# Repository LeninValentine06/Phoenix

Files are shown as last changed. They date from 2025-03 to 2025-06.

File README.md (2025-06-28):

# LoRa-Based Real-Time Landslide Detection System
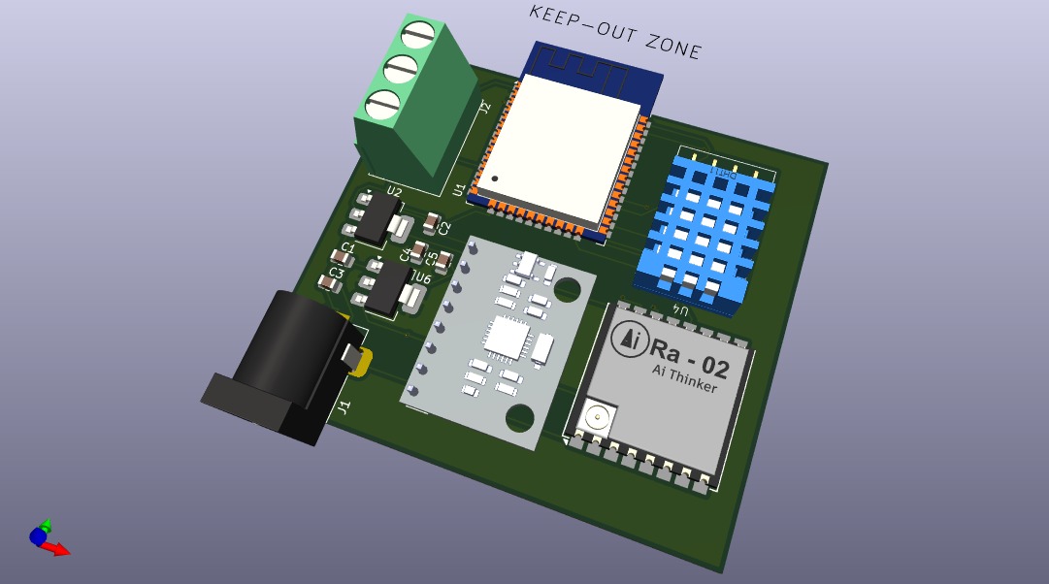
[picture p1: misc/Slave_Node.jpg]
Slave Node PCB Design
   
   *Figure 1: Slave Node PCB Design*

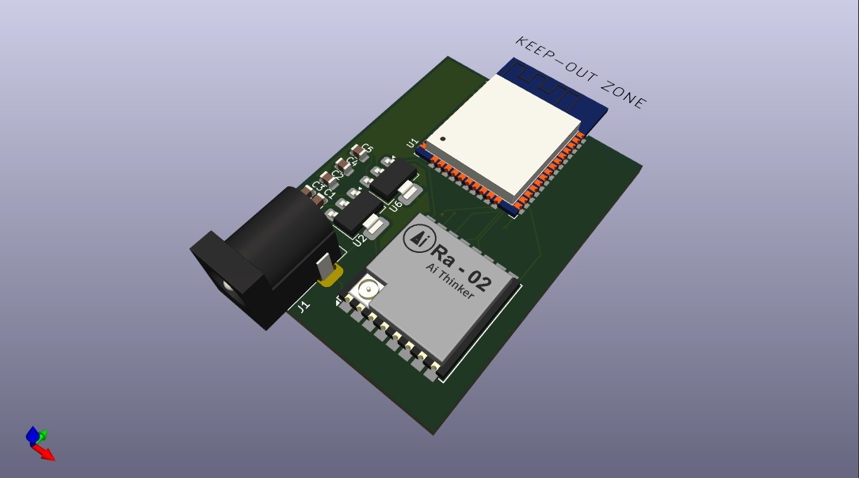
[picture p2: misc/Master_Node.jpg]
Master Node PCB Design
   
   *Figure 2: Master Node PCB Design*

## 1. Project Overview

### The Problem

Landslides are devastating natural disasters that claim thousands of lives annually worldwide. Traditional monitoring systems are often expensive, difficult to deploy in remote areas, and lack real-time alerting capabilities. Many vulnerable communities, especially in developing regions, lack access to early warning systems that could save lives.

### Our Solution

The LoRa-Based Real-Time Landslide Detection System provides an affordable, open-source solution for early detection and warning of potential landslide events. By combining low-power sensors, long-range wireless communication, and intelligent data processing, our system can:

- Detect early signs of land movement and soil condition changes
- Transmit data over long distances even in remote areas
- Provide immediate, multi-modal alerts to communities at risk
- Operate for extended periods on battery power

The system uses distributed ESP32-based sensor nodes placed in landslide-prone areas to continuously monitor ground movement, soil moisture, and environmental conditions. When potential landslide indicators are detected, the system triggers immediate alerts via multiple channels.

## 2. System Architecture

### Hardware Components

#### Sensor Node (ESP32)
- **Microcontroller**: ESP32-WROOM-32
- **Sensors**:
  - MPU6050 (3-axis accelerometer and gyroscope)
  - Capacitive soil moisture sensor
  - DHT22/AM2302 temperature and humidity sensor
- **Communication**: LoRa RA-02 module (433MHz)
- **Power**: 3.7V LiPo battery with solar charging capability

#### Master Node (ESP32)
- **Microcontroller**: ESP32-WROOM-32
- **Alert Mechanisms**:
  - 9V speaker/buzzer for audio alerts
  - 2.8" ILI9341 TFT display for visual alerts and status
  - Optional GSM module for SMS alerts
- **Communication**:
  - LoRa RA-02 module (433MHz)
  - WiFi/Bluetooth (for configuration and notifications)
- **Power**: 5V DC power supply with battery backup

### Data Flow Architecture

```
┌─────────────────┐     LoRa     ┌─────────────────┐     Alert     ┌─────────────────┐
│                 │  Wireless    │                 │   Triggers    │                 │
│   Sensor Node   │ ───────────► │   Master Node   │ ───────────► │  Alert Systems  │
│     (ESP32)     │    433MHz    │     (ESP32)     │               │   - Speaker     │
│                 │              │                 │               │   - Display     │
│                 │              │                 │               │   - Mobile      │
└─────────────────┘              └─────────────────┘               └─────────────────┘
        │                                 ▲
        │                                 │
        │         LoRa Wireless           │
        └─────────────────────────────────┘
                (Multiple Nodes)
```

1. **Data Collection**: The ESP32 sensor nodes continuously monitor accelerometer data (ground movement), soil moisture levels, and environmental conditions.
2. **Data Processing**: Initial data processing occurs on the sensor nodes to identify concerning patterns before transmission.
3. **Data Transmission**: Processed data is transmitted via LoRa to the master node.
4. **Alert Analysis**: The ESP32 master node analyzes data from multiple sensor nodes and determines if alert thresholds are exceeded.
5. **Alert Distribution**: When potential landslide conditions are detected, the master node activates local alerts and sends notifications to configured devices.

## 3. Features

### Real-time Environmental Monitoring
- Continuous accelerometer data collection at 50Hz sample rate
- Soil moisture monitoring with 5-minute intervals
- Temperature and humidity readings every 15 minutes
- Local data processing to detect movement patterns indicative of landslides

### Long-Range, Low-Power Communication
- LoRa communication with 3-10km range (depending on terrain) using 433MHz frequency
- Optimized data packets to minimize transmission power
- Node power management for extended battery life (3-6 months on a single charge with solar support)
- Reliable mesh networking capabilities between multiple sensor nodes

### Multi-Modal Alert System
- High-decibel audio alarm for immediate local warning
- Visual alerts and system status on TFT display
- Optional mobile alerts via SMS or app notifications
- Configurable alert thresholds based on local conditions

### System Scalability
- Support for up to 50 sensor nodes per master node
- Expandable with multiple master nodes for larger coverage areas
- Modular design allowing for additional sensor types
- Open API for integration with existing warning systems

## 4. Setup & Installation

### Prerequisites

#### Hardware Requirements
- ESP32 development boards (for both sensor and master nodes)
- MPU6050 accelerometer/gyroscope module
- Soil moisture sensor (capacitive recommended)
- DHT22/AM2302 temperature & humidity sensor
- LoRa RA-02 modules (433MHz)
- 2.8" ILI9341 TFT display
- 9V speaker/buzzer
- 3.7V LiPo batteries with solar charging modules
- Power supplies, jumper wires, and prototyping boards

#### Software Requirements
- Arduino IDE (for ESP32 programming)
- Required libraries (included in the repository):
  - RadioHead library for LoRa communication
  - Adafruit MPU6050 library
  - Adafruit DHT sensor library
  - Adafruit GFX & ILI9341 libraries

### Sensor Node Setup

1. **Hardware Assembly**

   Connect the components to the ESP32 according to this pinout:
   
   ```
   ESP32 (Sensor Node)   |     Component
   ------------------------------------
   GPIO21 (SDA)         ---    MPU6050 SDA
   GPIO22 (SCL)         ---    MPU6050 SCL
   GPIO36 (ADC0)        ---    Soil Moisture Sensor
   GPIO17               ---    DHT22 Data
   GPIO5 (SCK)          ---    RA-02 SCK
   GPIO23 (MOSI)        ---    RA-02 MOSI
   GPIO19 (MISO)        ---    RA-02 MISO
   GPIO18               ---    RA-02 CS
   GPIO14               ---    RA-02 RST
   GPIO26               ---    RA-02 DIO0
   5V                   ---    Battery + (via switch)
   GND                  ---    Common ground
   ```
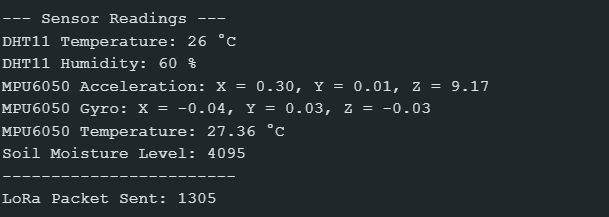
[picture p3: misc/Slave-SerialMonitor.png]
Slave Node Serial Monitor Output

*Figure 3: Serial Monitor Output from Slave Node showing sensor readings and LoRa transmission*

2. **Software Installation**

   a. Setup Arduino IDE for ESP32:
   - Add ESP32 board support to Arduino IDE
   - Install required libraries through the Library Manager

   b. Upload the sensor node code:
   - Clone this repository: `git clone https://github.com/LeninValentine06/lora-landslide-detection.git`
   - Navigate to the `sensor_node` directory
   - Open the `sensor_node.ino` file
   - Select your ESP32 board model and port
   - Compile and upload the code

### Master Node Setup

1. **Hardware Assembly**

   Connect the components to the ESP32 according to this pinout:
   
   ```
   ESP32 (Master Node)   |     Component
   ------------------------------------
   GPIO5 (SCK)          ---    RA-02 SCK
   GPIO23 (MOSI)        ---    RA-02 MOSI
   GPIO19 (MISO)        ---    RA-02 MISO
   GPIO18               ---    RA-02 CS
   GPIO14               ---    RA-02 RST
   GPIO26               ---    RA-02 DIO0
   GPIO25               ---    Speaker +
   GPIO21 (SDA)         ---    Display SDA
   GPIO22 (SCL)         ---    Display SCL
   GPIO2                ---    Display DC
   GPIO4                ---    Display CS
   GPIO15               ---    Display RST
   5V                   ---    Power input
   GND                  ---    Common ground
   ```
Master Node Serial Monitor Output
*Figure 4: Serial Monitor Output from Master Node showing received data and alert status*

2. **Software Installation**

   a. Setup Arduino IDE for ESP32:
   - Add ESP32 board support to Arduino IDE
   - Install required libraries through the Library Manager

   b. Upload the master node code:
   - Open the `/master_node/master_node.ino` file from the repository
   - Select your ESP32 board model and port
   - Compile and upload the code

### Optional Mobile Notification Setup

1. Install the companion mobile app (available in the `/mobile_app` directory)
2. Configure WiFi credentials in the master node code
3. Pair your smartphone with the master node using the app
4. Test the notification system by triggering a test alert

## 5. Usage Instructions

### Initial Configuration

1. Place sensor nodes in strategic locations based on landslide risk assessment
   - Ensure proper anchoring into stable ground
   - Position solar panels for optimal sunlight exposure
   - Maintain line-of-sight between nodes when possible

2. Power on the master node first, then the sensor nodes
   - The master node display will show initialization progress
   - Wait for "SYSTEM READY" message on the display

3. Configure alert thresholds using the master node interface:
   - Press the CONFIG button to enter setup mode
   - Adjust sensitivity, alert levels, and communication parameters
   - Save configuration when complete

### Normal Operation

Under normal conditions, the system will:
- Display current readings from all sensor nodes
- Show battery levels and signal strength
- Log data at regular intervals
- Perform automatic self-tests every 24 hours

The TFT display shows a grid of connected sensor nodes with their status. Green indicators show normal operation, yellow shows warning levels, and red indicates critical alerts.

### Alert Conditions

When potential landslide conditions are detected:

1. The master node will:
   - Activate the audio alarm
   - Display detailed alert information
   - Send notifications to paired mobile devices
   - Log the event with timestamp and sensor data

2. To acknowledge alerts:
   - Press the ACKNOWLEDGE button on the master node
   - The audio alarm will silence, but visual alerts remain
   - The system continues monitoring for worsening conditions

3. After the danger passes:
   - Press and hold RESET for 5 seconds
   - Confirm system reset when prompted
   - The system will return to normal monitoring mode

## 6. Contributing

Contributions to this project are welcome! Here's how you can help:

### Reporting Issues
- Use the GitHub issue tracker to report bugs
- Include detailed steps to reproduce the issue
- Attach logs or screenshots when available

### Pull Requests
1. Fork the repository
2. Create a new branch (`git checkout -b feature/your-feature-name`)
3. Make your changes
4. Run tests if available
5. Commit your changes (`git commit -m 'Add some feature'`)
6. Push to the branch (`git push origin feature/your-feature-name`)
7. Open a Pull Request

### Development Guidelines
- Follow existing code style and naming conventions
- Add comments to explain complex functionality
- Update documentation when making changes
- Add tests for new features when possible

## 7. License

This project is licensed under the Creative Commons Zero v1.0 Universal License - see the [LICENSE](LICENSE) file for details.

This means you can copy, modify, distribute and perform the work, even for commercial purposes, all without asking permission.

---

**Disclaimer**: This system is designed as an early warning tool but should not replace proper evacuation procedures or professional geological assessment. Always follow local authority guidance during emergency situations.

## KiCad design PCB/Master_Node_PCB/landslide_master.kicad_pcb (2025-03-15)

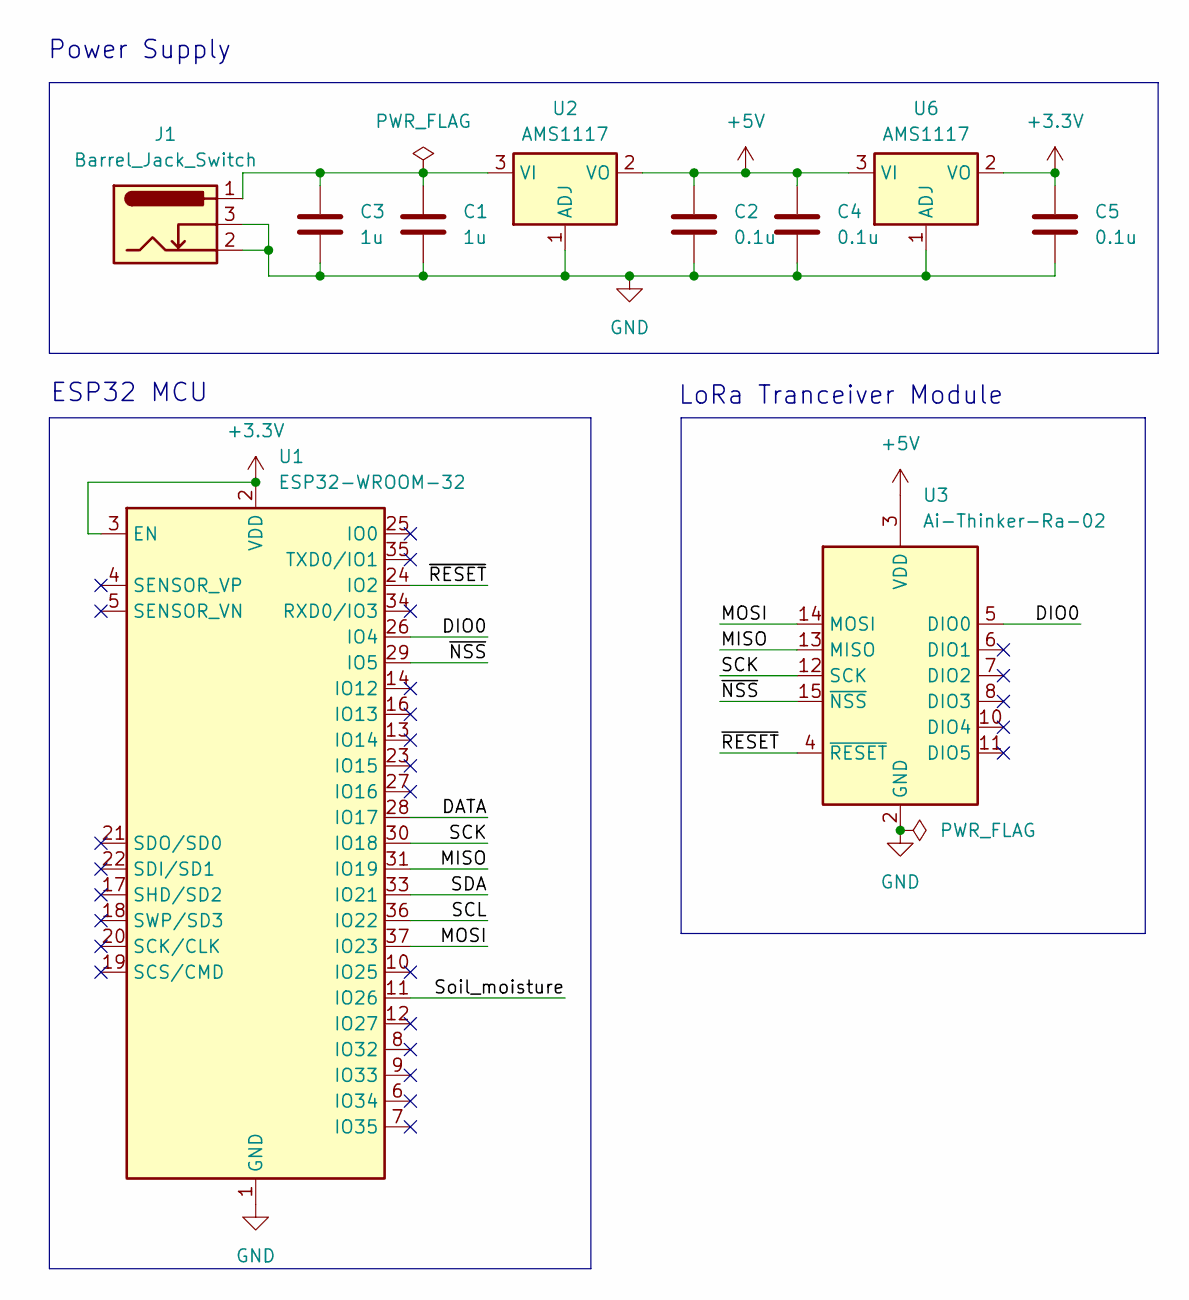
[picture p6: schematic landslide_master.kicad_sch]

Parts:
C1, C3: 1u; C_0805_2012Metric
C2, C4, C5: 0.1u; C_0805_2012Metric
J1: Barrel_Jack_Switch; BarrelJack_Horizontal
U1: ESP32-WROOM-32
U2, U6: AMS1117; SOT-223-3_TabPin2
U3: Ai-Thinker-Ra-02; Ai-Thinker-Ra-01-LoRa

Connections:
+3.3V: C5.1, U1.2 (VDD), U1.3 (EN), U6.2 (VO)
+5V: C2.1, C4.1, U2.2 (VO), U3.3 (VDD), U6.3 (VI)
/DATA: U1.28 (IO17)
/DIO0: U1.26 (IO4), U3.5 (DIO0)
/MISO: U1.31 (IO19), U3.13 (MISO)
/MOSI: U1.37 (IO23), U3.14 (MOSI)
/SCK: U1.30 (IO18), U3.12 (SCK)
/SCL: U1.36 (IO22)
/SDA: U1.33 (IO21)
/Soil_moisture: U1.11 (IO26)
/~NSS: U1.29 (IO5), U3.15 (~NSS)
/~RESET: U1.24 (IO2), U3.4 (~RESET)
GND: C1.2, C2.2, C3.2, C4.2, C5.2, J1.2, J1.3, U1.1 (GND), U1.15 (GND), U1.38 (GND), U1.39 (GND), U2.1 (ADJ), U3.1 (GND), U3.2 (GND), U3.9 (GND), U3.16 (GND), U6.1 (ADJ)
unnamed: C1.1, C3.1, J1.1, U2.3 (VI)

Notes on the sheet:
ESP32 MCU
Power Supply
LoRa Tranceiver Module

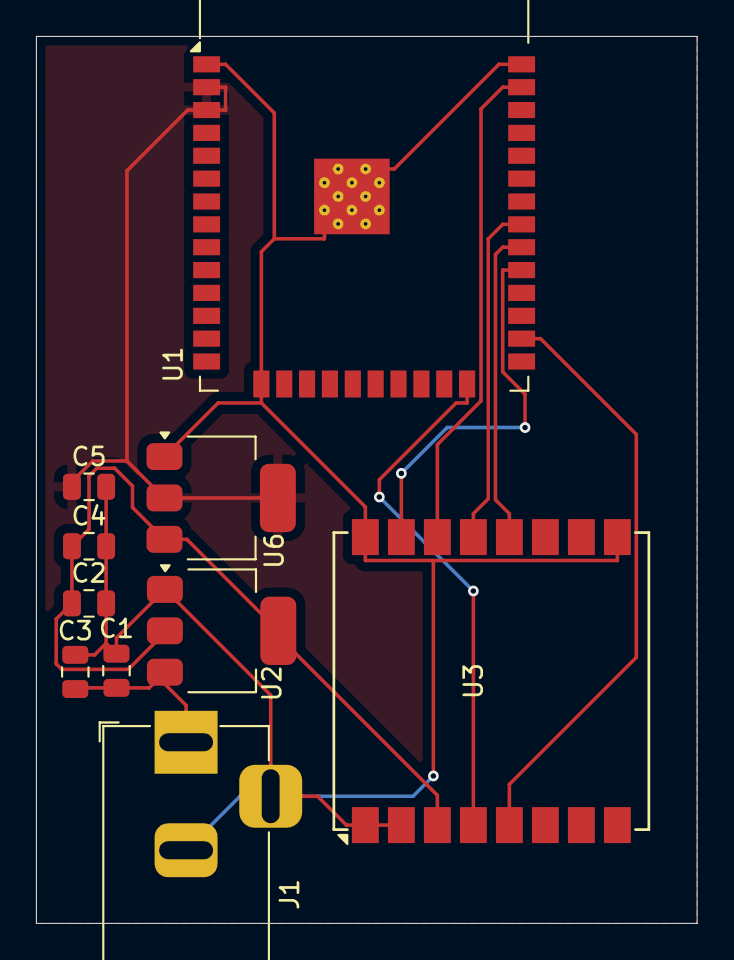
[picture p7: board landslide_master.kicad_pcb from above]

Board: 2 copper layers, 36.7 x 49.3 mm, 10 parts (0 on the bottom side), 10 nets.

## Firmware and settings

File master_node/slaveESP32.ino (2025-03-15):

/**
 * MPU6050 + DHT11 + Soil Moisture Sensor + LoRa Transmitter
 * Reads accelerometer, gyroscope, and temperature from MPU6050
 * Reads temperature and humidity from DHT11
 * Reads soil moisture level from analog sensor
 * Sends data via LoRa communication
 * 
 * Author: Lenin Valentine
 */

#include <Adafruit_MPU6050.h>
#include <Adafruit_Sensor.h>
#include <Wire.h>
#include <DHT11.h>
#include <SPI.h>
#include <LoRa.h>

// DHT11 & Soil Moisture Pins
#define DHT_PIN 14           // DHT11 sensor pin
#define SOIL_MOISTURE_PIN 34  // Soil Moisture Sensor connected to GPIO34

// LoRa Pins
#define PIN_LORA_COPI   23
#define PIN_LORA_CIPO   19
#define PIN_LORA_SCK    18
#define PIN_LORA_CS     5
#define PIN_LORA_RST    2
#define PIN_LORA_DIO0   4
#define LORA_FREQUENCY  433E6  // LoRa Frequency

// Sensor Objects
DHT11 dht11(DHT_PIN);
Adafruit_MPU6050 mpu;
int counter = 0;

void setup() {
    Serial.begin(115200);
    Wire.begin(21, 22);  // ESP32 I2C: SDA = GPIO21, SCL = GPIO22

    // Initialize MPU6050
    Serial.println("Initializing MPU6050...");
    if (!mpu.begin()) {
        Serial.println("Failed to find MPU6050");
        while (1);
    }
    Serial.println("MPU6050 Initialized!");

    mpu.setAccelerometerRange(MPU6050_RANGE_8_G);
    mpu.setGyroRange(MPU6050_RANGE_500_DEG);
    mpu.setFilterBandwidth(MPU6050_BAND_21_HZ);

    // Initialize LoRa
    Serial.println("Initializing LoRa...");
    LoRa.setPins(PIN_LORA_CS, PIN_LORA_RST, PIN_LORA_DIO0);
    LoRa.setSPIFrequency(20000000);
    LoRa.setTxPower(20);

    if (!LoRa.begin(LORA_FREQUENCY)) {
        Serial.println("Starting LoRa failed!");
        while (1);
    }
    Serial.println("LoRa Initialized!");
}

void loop() {
    // Read MPU6050 Data
    sensors_event_t a, g, temp;
    mpu.getEvent(&a, &g, &temp);

    // Read DHT11 Data
    int temperature = 0, humidity = 0;
    int result = dht11.readTemperatureHumidity(temperature, humidity);

    // Read Soil Moisture Sensor
    int soilMoistureValue = analogRead(SOIL_MOISTURE_PIN);

    // Print Data Locally
    Serial.println("\n--- Sensor Readings ---");
    
    if (result == 0) {
        Serial.print("DHT11 Temperature: ");
        Serial.print(temperature);
        Serial.println(" °C");

        Serial.print("DHT11 Humidity: ");
        Serial.print(humidity);
        Serial.println(" %");
    } else {
        Serial.println(DHT11::getErrorString(result));
    }

    Serial.print("MPU6050 Acceleration: X = ");
    Serial.print(a.acceleration.x);
    Serial.print(", Y = ");
    Serial.print(a.acceleration.y);
    Serial.print(", Z = ");
    Serial.println(a.acceleration.z);

    Serial.print("MPU6050 Gyro: X = ");
    Serial.print(g.gyro.x);
    Serial.print(", Y = ");
    Serial.print(g.gyro.y);
    Serial.print(", Z = ");
    Serial.println(g.gyro.z);

    Serial.print("MPU6050 Temperature: ");
    Serial.print(temp.temperature);
    Serial.println(" °C");

    Serial.print("Soil Moisture Level: ");
    Serial.println(soilMoistureValue);

    Serial.println("------------------------");

    // Send Data via LoRa
    LoRa.beginPacket();
    LoRa.print("Packet ");
    LoRa.print(counter);
    LoRa.print(" | Temp: ");
    LoRa.print(temperature);
    LoRa.print("C | Humidity: ");
    LoRa.print(humidity);
    LoRa.print("% | Soil: ");
    LoRa.print(soilMoistureValue);
    LoRa.print(" | MPU Temp: ");
    LoRa.print(temp.temperature);
    LoRa.println("C");
    LoRa.endPacket();

    Serial.print("LoRa Packet Sent: ");
    Serial.println(counter);
    
    counter++;
    delay(1000);  // 1 second delay
}

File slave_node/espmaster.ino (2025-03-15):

#include <SPI.h>
#include <LoRa.h>

#define PIN_LORA_CS 5
#define PIN_LORA_RST 2
#define PIN_LORA_DIO0 4
#define LORA_FREQUENCY 433E6

void setup() {
    Serial.begin(115200);
    Serial.println("LoRa Receiver Initializing...");

    LoRa.setPins(PIN_LORA_CS, PIN_LORA_RST, PIN_LORA_DIO0);
    LoRa.setSPIFrequency(1E6);  // Reduce SPI speed

    if (!LoRa.begin(LORA_FREQUENCY)) {
        Serial.println("LoRa Initialization Failed!");
        while (1);
    }

    Serial.println("LoRa Receiver Ready");
}

void loop() {
    int packetSize = LoRa.parsePacket();
    if (packetSize) {
        Serial.println(" Packet Detected!");

        String receivedData = "";
        while (LoRa.available()) {
            char c = (char)LoRa.read();
            receivedData += c;
        }

        Serial.print("Received Data: ");
        Serial.println(receivedData);
        Serial.print("RSSI: ");
        Serial.println(LoRa.packetRssi());

        Serial.println("----------------------");
    }
}

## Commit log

2025-03-15 Added PCB files
    [LandSlide_detection.kicad_pcb, LandSlide_detection.kicad_sch]
2025-03-15 Updated files
    [landslide_master.kicad_pcb, landslide_master.kicad_sch]
